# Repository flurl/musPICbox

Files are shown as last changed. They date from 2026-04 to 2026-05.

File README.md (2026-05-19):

# musPICbox

Dies ist das Sourcecode Repository zu meinem Artikel in [Make](https://www.heise.de/make) 3/26, Seite 88.

Außerdem finden Sie hier eine detailiertere Anleitung zum Konfigurieren des µC mit dem MPLAB Code Configurator.

Make Magazin Logo (https://www.heise.de/make)

## Konfiguration des PIC mittels MCC

Der MPLAB Code Configurator ermöglicht die grafische Konfiguration diverser Peripherie (Clock, Timer, ADC, PWM etc.) des Microcontrollers per Mausklick. Aus den getroffenen Einstellungen erzeugt der MCC Initialisierungscode, der die Register korrekt setzt und Helferfunktionen bereitstellt.

Die Konfiguration der Pins für die LEDs veranschaulicht diesen Prozess. Nach dem Start des MCC befindet man sich in dessen Hauptfenster, dem `Application Builder`. Hier wird eine grafische Repräsentation der Firmware angezeigt. Der oberste Abschnitt zeigt alle vom User hinzugefügten Komponenten an. Momentan ist das nur die Datei `main.c`. Der mit `System` beschriftete Bereich listet die in Verwendung befindlichen System Treiber. Darunter ist der Device Abschnitt, der Infos über die MCU und ihre Fähigkeiten anzeigt. Die weißen ? auf blauen Hintergrund führen direkt zur Online Dokumentation der jeweiligen Komponenten oder UI-Elemente - sehr praktisch.

Durch einen Klick auf den `Pins` System Treiber öffnet man die `Pin Package View`. Links oben gibt es ein mit "Package" beschriftetes Drop-Down, womit man die Gehäuseform des µC festlegen kann. Wir wählen PDIP20, woraufhin im Arbeitsbereich ein Piktogramm des Chips dargestellt wird. Dem Schaltplan ist zu entnehmen, dass die LEDs mit den GPIOs `RC0`, `RC1` sowie `RC2` verbunden werden. Um dies dem MCC mitzuteilen, klicken wir nacheinander auf die entsprechenden Pins des Symbolbildes, woraufhin ein Pop-Up erscheint, mit dem wir den Pins die Funktion "GPIO | GPIO | Output" zuweisen. Daraufhin wird für jeden Pin im rechten Fenster eine Zeile zur weiteren Konfiguration hinzugefügt. In der Spalte `Custom Name` kann man einen Alias für den jeweiligen IO-Port hinterlegen, den man im Quellcode verwenden kann. Ich habe ihnen dem Schaltplan entsprechend die Namen "LED_RED", "LED_BLUE" und "LED_GREEN" zugewiesen . Außerdem ist bei allen drei LED Pins die Option `Start High` zu aktivieren. Die sorgt dafür, dass die Pins beim Booten bereits auf High gesetzt werden, was, da die LEDs "active-low" verdrahtet sind, den Effekt hat, dass keine der LEDs leuchtet.

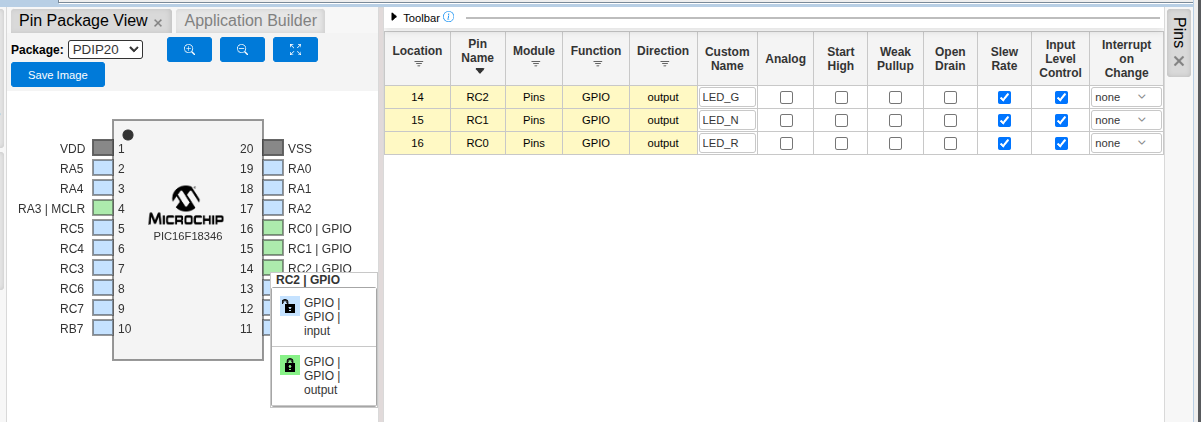
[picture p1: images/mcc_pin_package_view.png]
MCC Pin Package View label:mcc_pin_package_view


Danach wählt man am linken Rand des MCC den Tab `Project Resource` und klickt auf den blauen Button `Generate` im linken oberen Eck. Im `Output` Fenster sieht man, welche Aktionen der MCC sodann ausführt. So erstellt er diverse Dateien im Unterverzeichnis `mmcc_generated_files/system`. In eben jenem Verzeichnis findet sich nun auch eine Datei `pins.h`. Deren Inhalt illustriert, welche Arbeit der MCC für einen übernimmt. Vor allem erstellt der MCC eine Menge Präprozessordirektiven, die uns das lästige direkte hantieren mit den Registern des Prozessors ersparen und den Umgang mit der Peripherie wesentlich vereinfachen.

Die Zeile

```C
#define LED_RED_SetHigh() do { LATCbits.LATC0 = 1; } while(0)
```

ermöglicht es beispielsweise, den Pin, an dem die rote LED hängt (hier kommen die `Custom Names` ins Spiel), durch ein simples `LED_RED_SetHigh()` im C-Code auf High zu setzen. Das Macro `LED_RED_SetHigh()` wird dabei durch den etwas seltsam anmutenden `do ... while(0)` Block ersetzt. Dieser setzt des Bit 0 im `LATC` Register auf 1 und damit den Pin auf High. Die Konstruktion mit der do-while-Schleife hat syntaktische Gründe.

Der MCC ist auch die passende Anlaufstelle um die Frequenz, mit der µC läuft einzustellen. Die Frequenzen, die wir für die Erzeugung der Töne benötigen, liegen im niedrigen kHz Bereich. Es ergibt daher wenig sinn, den PIC mit vollem Speed laufen zu lassen. Je langsamnr, desto niedriger der Stromverbrauch. Ein Klick auf das `Clock Control` Modul ermöglicht es, den Takt mit dem Dropdown `HF Internal Clock` auf 1MHz zu setzen.

Um die weiteren GPIOs zu konfigurieren gehen wir nach dem selben Muster vor. Dem Schaltplan nach wird der Taster mit dem Pin `RA2` verbunden. Also klicken wir im `Pin Package View` des MCC auf das Symbol des entsprechenden Pins und weisen ihm die Funktion "GPIO | Input" zu. Als `Custom Name` verwende ich "PIN_BTN". Außerdem setze ich das Häckchen bei `Weak Pullup`, womit der interen Pullup Widerstand aktiviert wird.

Damit ist der "einfache" Part der Konfiguration erledigt. Nun gilt es noch zwei Probleme zu lösen. Das erste ist, dass, um eine wirklich (pseudo)-zufällige Wiedergabe zu ermöglichen, wir noch einen Seed für den Zufallsgenerator benötigen. Dafür machen wir uns einen floatenden analogen Eingang zu nutze. Floatend bedeutet, dass er nicht weiter verdrahtet und somit nur einem Zufallsrauschen ausgesetzt ist. Dafür müssen wir zuerst ins `Application Builder` Fenster zurück und mittels des Knopfes `⊕Add Component` den Add Component Dialog aufrufen. Am besten filtert man in diesem die Liste der verfügbaren Komponenten, indem man ins Suchfeld den Begriff "ADC" eingibt. In den Suchergebnissen klickt man schließlich in der Zeile des ADC Moduls ganz rechts auf das ⊕ Symbol, woraufhin sich der Dialog schließt und im `Application Builder` View das neu hinzugefügte Modul unter Main angezeigt wird. Mit dem blauen Zahnradsymbol in der rosanen Komponentenbox gelangt man zur Konfiguation des ADC. Wir belassen alles auf den Standardwerten, aber ein Blick auf die angebotenen Möglichkeiten lohnt sich allemal.

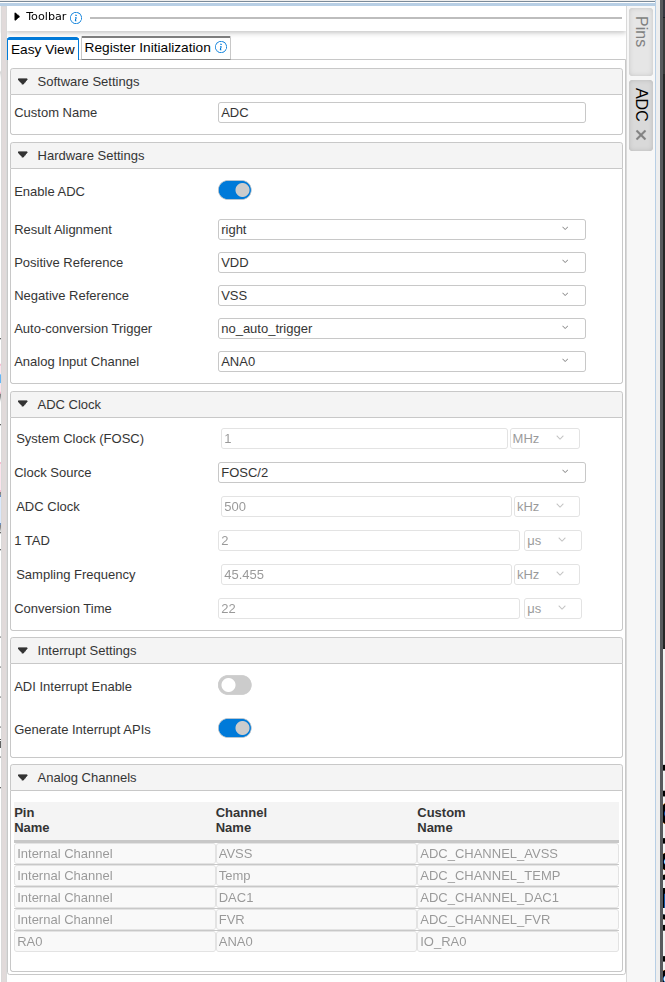
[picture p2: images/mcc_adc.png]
MCC ADC Konfiguration label:mcc_adc


Im `Pins`-Reiter sieht man auch, dass der Pin `RA0` automatisch dem ADC Modul zugewiesen wurde.

Was jetzt noch fehlt sind die zwei Pins, die das PWM Signal ausgeben sollen. Dazu sind zwei weitere Komponenten notwendig, die man wieder im `Application Builder` mittels `⊕Add Component` hinzufügen kann. Das erste ist das "CCP1" (Capture/Compare/PWM) Modul, das zweite heißt "CLC1" (Configurable Logic Cell). Nach beiden sucht man im Add Component Dialog und inkludiert sie ins Projekt mit ⊕.

Das blaue Zahnradsymbol beim "CCP1" Modul öffnet dessen Konfigurationsoptionen am rechten Rand. Den `CCP Mode` setzen wir auf PWM, was neue Optionen zum Vorschein bringt. Wählen wir nun im `TMR Dependency Selector` "TMR2" aus, wird der Timer2 als Abhängigkeit zu den Projektresourcen hinzugefügt (Reiter am linken Rand des MCC). Da die PWM und Timer Konfiguration dynamisch während des Programmablaufs geändert wird, können wir die restlichen Einstellungen auf dem Standard belassen.

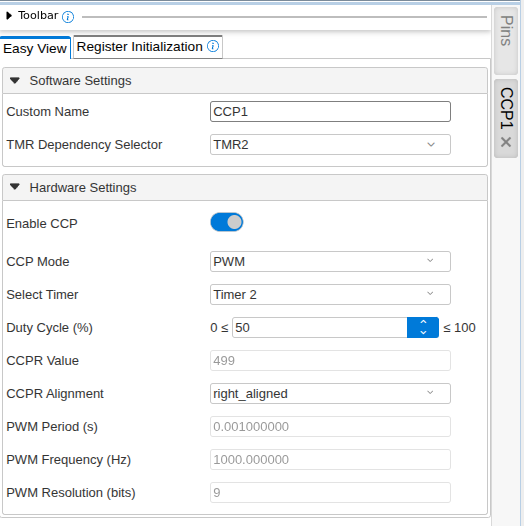
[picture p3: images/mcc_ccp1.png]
MCC Timer Konfiguration label:mcc_ccp1


Fehlt noch das CLC1 Modul. Wie bereits erwähnt, ermöglicht dieses, diverse Input Signale mit Logikblöcken zu verbinden und daraus ein Ausgangsignal zu generieren - ganz unabhängig vom Programmcode. Ein Klick auf die Komponente im `Application Builder` öffnet wiederum die Einstellungen des Moduls. Im `Logic Cell Mode bits` Dropdown bietet sich die "4-input-AND" Schaltung an. Sobald man sie ausgewählt hat, updated sich der Schaltplan im unteren Fenster und zeigt den Aufbau der Logikschaltung. Die mag auf den ersten Blick etwas ehrfurchtgebietend wirken, ist aber gar nicht kompliziert, wenn man sich in kleinen Schritten herantastet.

Unser Ziel ist es, das PWM Signal zu invertieren. Also ist es nur logisch, dass das PWM Signal als Input herhalten muss. Dafür reicht es, im ersten Dropdown den Ouptut des "CCP1" Moduls auszuwählen. Die erste Stufe der Schaltung besteht aus vier vierfach ODER Verknüpfungen, die zweite aus einer vierfach UND Verknüpfung und die dritte aus einem Buffer. Wenn man nun das Eingangssignal mit allen vier ODER Verknüpfungen verbindet, in dem man auf das strichlierte Quadrat auf der Eingangsseite der ODER Symbole klickt, bis sie mit dem Eingangssignal durch eine durchgehende Linie verbunden sind, wird das Signal direkt an alle vier Eingänge des AND Logikblocks angelegt. Das heißt, spuckt das "CCP1" eine 1 aus, liegt auch am Ausgang des ANDs eine 1 an. Diese wird nun noch durch den Buffer geschickt - der nichts anderes macht, als das Eingangssignal an seinen Ausgang durchzureichen - und wir erhalten am Ausgang der Logikzelle eine Kopie des Eingangssignals. Ziel fast erreicht; durch einen Klick auf das strichlierte Quadrat am Ausgang des Buffers fügen wir noch ein NOT-Gate hinzu, welches das Ausgangsignal des Buffers invertiert. Und somit ist nun das Ausgangssignal des "CLC1" Moduls stets invertiert zum PWM Signal.

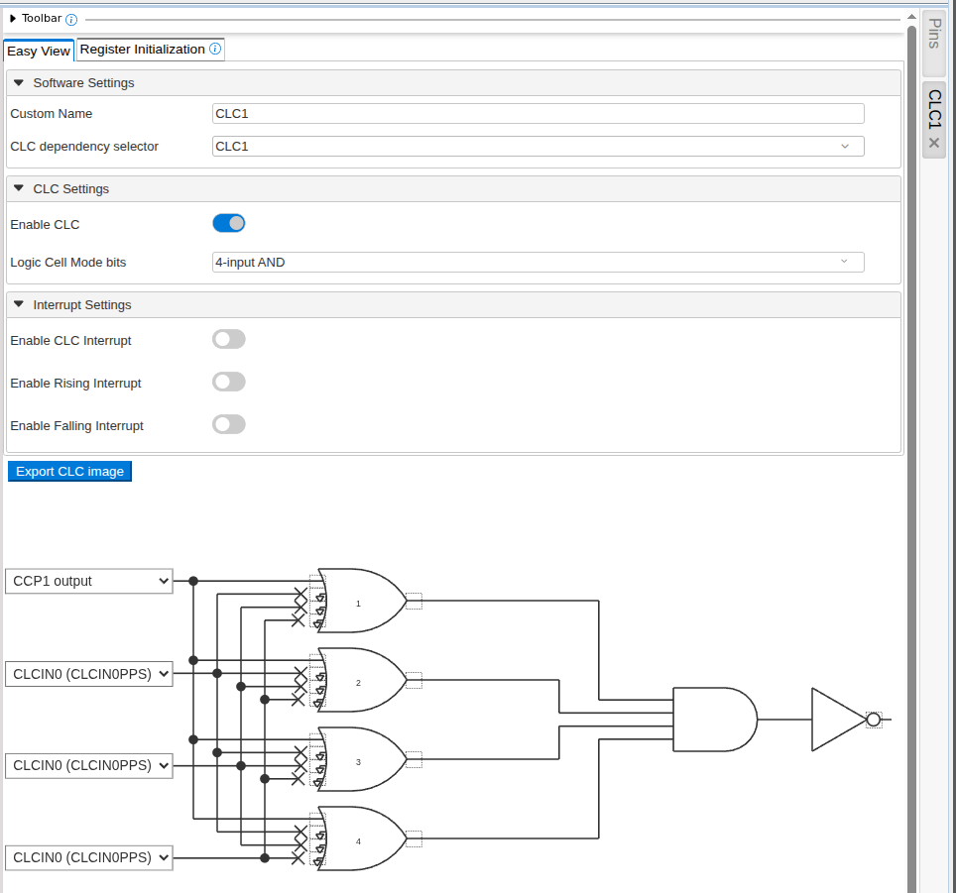
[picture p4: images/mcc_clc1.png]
CLC1 Konfiguration label:mcc_clc1


Als letzten Schritt müssen noch die Ausgänge der Module den entsprechenden Pins zugewiesen werden. Also zurück zur `Pin Package View`. Der Buzzer ist laut Schaltplan mit den Pins `RC3` und `RC4` verbunden. Deshalb weisen wir einem von ihnen "CCP1 | CCP1OUT | output" zu, und dem anderen "CLC1 | CLC1 | output". Welcher welche Rolle übernimmt ist egal, da sie immer gegengleich betrieben werden.

Somit ist das Setup im MCC abgeschlossen und mit der `Generate`-Schaltfläche lassen wir die notwendigen Dateien vom MCC erzeugen.

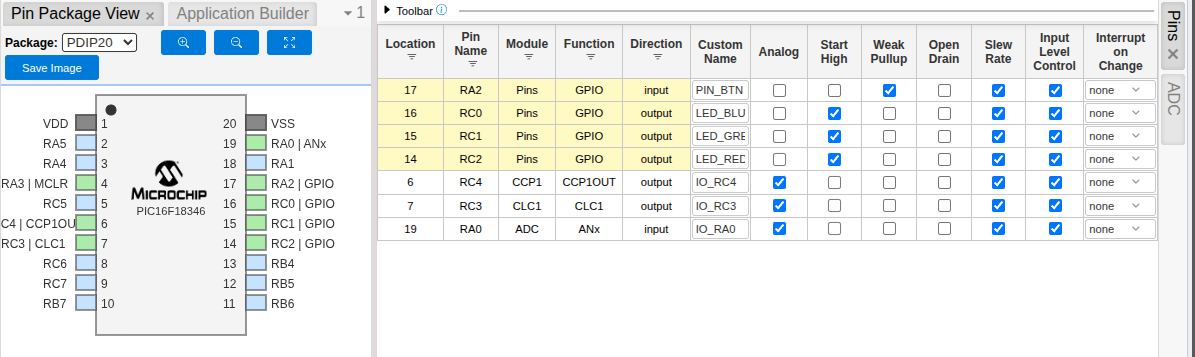
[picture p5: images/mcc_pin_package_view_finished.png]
MCC Pin Package View Einstellungen label:mcc_pin_package_view_finished


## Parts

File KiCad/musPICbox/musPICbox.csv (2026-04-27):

Id | Designator | Footprint | Quantity | Designation | Supplier and ref
1 | D8 | D_SOD-323_HandSoldering | 1 | D_Zener 5.1V
2 | D5,D7,D6,D4 | D_SMA_Handsoldering | 4 | D_Schottky
3 | D9 | LED_RGB_Wuerth-PLCC4_3.2x2.8mm_150141M173100 | 1 | LED_ARGB
4 | C1 | CP_Elec_10x10.5 | 1 | 1000µ
5 | BZ1 | JST_GH_BM02B-GHS-TBT_1x02-1MP_P1.25mm_Vertical | 1 | Buzzer
6 | R1 | R_0805_2012Metric_Pad1.20x1.40mm_HandSolder | 1 | 470
7 | C2 | C_0805_2012Metric_Pad1.18x1.45mm_HandSolder | 1 | 0.1µ
8 | M1 | JST_GH_BM02B-GHS-TBT_1x02-1MP_P1.25mm_Vertical | 1 | Motor_DC
9 | SW1 | JST_GH_BM02B-GHS-TBT_1x02-1MP_P1.25mm_Vertical | 1 | SW_Push
10 | U1 | DIP-20_W7.62mm | 1 | PIC16F18346-P

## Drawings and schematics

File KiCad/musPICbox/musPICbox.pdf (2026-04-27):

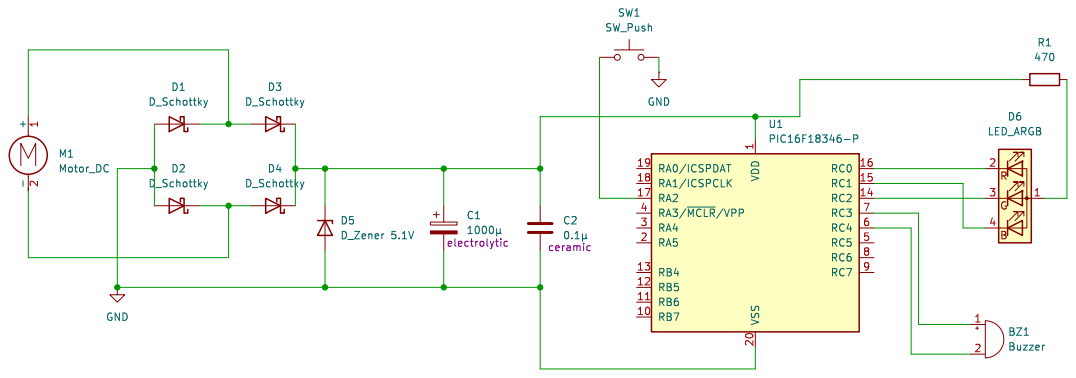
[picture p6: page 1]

Id: 1/1 Title: File: musPICbox.kicad_sch Sheet: /

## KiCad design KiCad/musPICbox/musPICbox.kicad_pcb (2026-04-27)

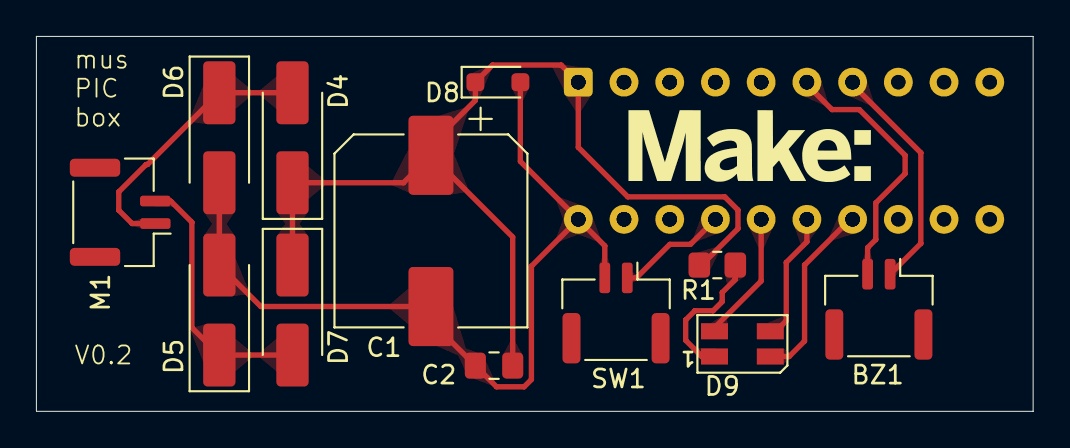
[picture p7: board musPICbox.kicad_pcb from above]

Board: 2 copper layers, 55.4 x 20.8 mm, 13 parts (1 on the bottom side), 11 nets.

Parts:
BZ1: Buzzer; JST_GH_BM02B-GHS-TBT_1x02-1MP_P1.25mm_Vertical
C1: 1000µ; CP_Elec_10x10.5
C2: 0.1µ; C_0805_2012Metric_Pad1.18x1.45mm_HandSolder
D4, D5, D6, D7: D_Schottky; D_SMA_Handsoldering
D8: D_Zener 5.1V; D_SOD-323_HandSoldering
D9: LED_ARGB; LED_RGB_Wuerth-PLCC4_3.2x2.8mm_150141M173100
M1: Motor_DC; JST_GH_BM02B-GHS-TBT_1x02-1MP_P1.25mm_Vertical
R1: 470; R_0805_2012Metric_Pad1.20x1.40mm_HandSolder
SW1: SW_Push; JST_GH_BM02B-GHS-TBT_1x02-1MP_P1.25mm_Vertical
U1: PIC16F18346-P; DIP-20_W7.62mm

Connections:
GND: C1.2, C2.2, D4.2 (A), D5.2 (A), D8.2 (A), SW1.2, U1.20 (VSS)
unnamed: BZ1.1 (+), U1.7 (RC3)
unnamed: BZ1.2 (-), U1.6 (RC4)
unnamed: D4.1 (K), D6.2 (A), M1.1 (+)
unnamed: D5.1 (K), D7.2 (A), M1.2 (-)
unnamed: C1.1, C2.1, D6.1 (K), D7.1 (K), D8.1 (K), R1.2, U1.1 (VDD)
unnamed: D9.1 (A), R1.1
unnamed: D9.4 (BK), U1.15 (RC1)
unnamed: D9.3 (GK), U1.14 (RC2)
unnamed: D9.2 (RK), U1.16 (RC0)
unnamed: SW1.1, U1.17 (RA2)

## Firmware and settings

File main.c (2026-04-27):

 /*
 * MAIN Generated Driver File
 * 
 * @file main.c
 * 
 * @defgroup main MAIN
 * 
 * @brief This is the generated driver implementation file for the MAIN driver.
 *
 * @version MAIN Driver Version 1.0.2
 *
 * @version Package Version: 3.1.2
*/

/*
? [2026] Microchip Technology Inc. and its subsidiaries.

    Subject to your compliance with these terms, you may use Microchip 
    software and any derivatives exclusively with Microchip products. 
    You are responsible for complying with 3rd party license terms  
    applicable to your use of 3rd party software (including open source  
    software) that may accompany Microchip software. SOFTWARE IS ?AS IS.? 
    NO WARRANTIES, WHETHER EXPRESS, IMPLIED OR STATUTORY, APPLY TO THIS 
    SOFTWARE, INCLUDING ANY IMPLIED WARRANTIES OF NON-INFRINGEMENT,  
    MERCHANTABILITY, OR FITNESS FOR A PARTICULAR PURPOSE. IN NO EVENT 
    WILL MICROCHIP BE LIABLE FOR ANY INDIRECT, SPECIAL, PUNITIVE, 
    INCIDENTAL OR CONSEQUENTIAL LOSS, DAMAGE, COST OR EXPENSE OF ANY 
    KIND WHATSOEVER RELATED TO THE SOFTWARE, HOWEVER CAUSED, EVEN IF 
    MICROCHIP HAS BEEN ADVISED OF THE POSSIBILITY OR THE DAMAGES ARE 
    FORESEEABLE. TO THE FULLEST EXTENT ALLOWED BY LAW, MICROCHIP?S 
    TOTAL LIABILITY ON ALL CLAIMS RELATED TO THE SOFTWARE WILL NOT 
    EXCEED AMOUNT OF FEES, IF ANY, YOU PAID DIRECTLY TO MICROCHIP FOR 
    THIS SOFTWARE.
*/
#include <stdlib.h>

#include "mcc_generated_files/system/system.h"
#include "random.h"
#include "melodies.h"

// the melody that should be played when the button is pressed at startup
#define SIGNATURE_MELODY 0


inline void delay(uint32_t ms) {
    for (uint32_t i=1; i<=ms; i++) {
        __delay_ms(1);
    }
}


void seed_RNG() {
    uint32_t seed = 0;
    ADC_Enable();
    for (uint8_t i=0; i<32; i++) {
        ADC_ConversionStart();
        while(!ADC_IsConversionDone());
        seed |= ((ADC_ConversionResultGet() & 0x01) << i);
    }
    ADC_Disable();
    rng_seed(seed);
}


pitch_t get_max_pitch(const struct Note *notes, uint16_t size) {
    pitch_t max = 0;
    for (uint16_t i=0; i<size; i++) {
        if (notes[i].pitch > max) {
            max = notes[i].pitch;
        }
    }
    return max;
}

pitch_t get_min_pitch(const struct Note *notes, uint16_t size) {
    pitch_t min = 0xFFFF;
    for (uint16_t i=0; i<size; i++) {
        pitch_t p = notes[i].pitch;
        if (p < min && p != REST) {
            min = notes[i].pitch;
        }
    }
    return min;
}

void tone(pitch_t tone) {
    
    setup_pitch(tone);
    
}

void play_melody(const struct Melody *melody) {
    size_t length = melody->length;  
    pitch_t max = get_max_pitch(melody->notes, length);
    pitch_t min = get_min_pitch(melody->notes, length);
    pitch_t low_threshold = (max-min)/3 + min;
    pitch_t high_threshold = ((max-min)/3)*2 + min;
    
    for (int current_note = 0; current_note < length; current_note++) {
        if (PIN_BTN_GetValue() == LOW) {
            delay(1000);
            return;
        }
        struct Note n = melody->notes[current_note];
        tone(n.pitch);
        if (n.pitch > 0 && n.pitch < low_threshold) {LED_BLUE_SetLow();}
        else if (n.pitch >= low_threshold && n.pitch < high_threshold) {LED_GREEN_SetLow();}
        else if (n.pitch >= high_threshold) {LED_RED_SetLow();}
        delay((uint32_t)((melody->speed*n.value)>>5));
        LED_RED_SetHigh();
        LED_GREEN_SetHigh();
        LED_BLUE_SetHigh();
        tone(REST);
        delay(10);
    }
}


/*
    Main application
*/

int main(void)
{
    SYSTEM_Initialize();
    
    seed_RNG();
    
    uint8_t selected_melody = SIGNATURE_MELODY;
    // if the button is not pressed at boot, randomly select the starting melody
    if (PIN_BTN_GetValue() == HIGH) {
        selected_melody = (uint8_t)rng_uniform(NUM_MELODIES);
    }
    
    tone(NOTE_A4);
    LED_BLUE_SetLow();
    __delay_ms(300);
    LED_BLUE_SetHigh();
    tone(NOTE_A5);
    LED_GREEN_SetLow();
    __delay_ms(300);
    LED_GREEN_SetHigh();
    tone(NOTE_A6);
    LED_RED_SetLow();
    __delay_ms(300);
    LED_RED_SetHigh();
   
    tone(REST);
    delay(500);    
    
    while(1) {
        play_melody(&(melodies[selected_melody]));
        delay(1000);    
        selected_melody = (uint8_t)rng_uniform(NUM_MELODIES);
    }
}

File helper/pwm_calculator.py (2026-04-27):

# pwm_calculator.py

# This script calculates the optimal PR2 value and TMR2 prescaler
# for a desired PWM frequency on a PIC16F18326 microcontroller.

# The core formula for PWM frequency is:
# F_PWM = F_OSC / (4 * (PR2 + 1) * TMR2_Prescaler)
# We rearrange this to solve for PR2:
# PR2 = (F_OSC / (4 * F_PWM * TMR2_Prescaler)) - 1

import math
import sys

def calculate_pwm_values(f_osc, f_pwm):
    """
    Calculates the best PR2 and TMR2 prescaler values for a given frequency,
    finding the closest approximation if an exact solution is not available.

    Args:
        f_osc (float): The microcontroller's oscillator frequency in Hz.
        f_pwm (float): The desired PWM frequency in Hz.

    Returns:
        tuple or None: A tuple containing (PR2, prescaler, actual_f_pwm)
                       if a solution is found, otherwise None.
    """

    # List of possible TMR2 prescaler values
    prescalers = [1, 4, 16, 64]
    
    # List to store all valid solutions and their errors
    solutions = []

    # Iterate through each possible prescaler to find a valid PR2 value
    for prescaler in prescalers:
        # Check if F_PWM is zero to prevent division by zero errors
        if f_pwm == 0:
            continue
            
        # Calculate the required PR2 value as a float
        pr2_float = (f_osc / (4.0 * f_pwm * prescaler)) - 1
        
        # We use this method for rounding to ensure it behaves as expected,
        # especially with potential floating-point precision issues.
        pr2 = int(pr2_float + 0.5)
        
        # Check if the calculated integer PR2 is within the valid range (0-255)
        if 0 <= pr2 <= 255:
            # Calculate the actual PWM frequency for this combination
            actual_f_pwm = f_osc / (4.0 * (pr2 + 1) * prescaler)
            
            # Calculate the absolute difference (error)
            error = abs(f_pwm - actual_f_pwm)
            
            # Store the solution
            solutions.append({
                'pr2': pr2,
                'prescaler': prescaler,
                'actual_f_pwm': actual_f_pwm,
                'error': error
            })
            
    # If no solutions were found, return None
    if not solutions:
        return None
        
    # Find the solution with the smallest error
    best_solution = min(solutions, key=lambda x: x['error'])
    
    # Return the best PR2, prescaler, and the actual frequency
    return (best_solution['pr2'], best_solution['prescaler'], best_solution['actual_f_pwm'])

if __name__ == "__main__":
    try:
        # Check if command-line arguments were provided
        if len(sys.argv) == 3:
            # Use arguments if they exist
            f_osc = float(sys.argv[1]) * 1_000_000
            f_pwm = float(sys.argv[2]) * 1_000
        else:
            # Fall back to interactive input
            f_osc_input = input("Enter the oscillator frequency in MHz (e.g., 16): ")
            f_pwm_input = input("Enter the desired PWM frequency in kHz (e.g., 20): ")

            f_osc = float(f_osc_input) * 1_000_000  # Convert MHz to Hz
            f_pwm = float(f_pwm_input) * 1_000     # Convert kHz to Hz

        # Call the calculation function
        result = calculate_pwm_values(f_osc, f_pwm)

        if result:
            pr2, prescaler, actual_f_pwm = result
            print(f"    PR2 = {pr2};")
            if prescaler == 1:
                ps_bits = 0b00
            elif prescaler == 4:
                ps_bits = 0b01
            elif prescaler == 16:
                ps_bits = 0b10
            else:
                ps_bits = 0b11
            print(f"    T2CON = T2CON & 0b11111100 | ({ps_bits} << _T2CON_T2CKPS_POSN); // prescaler {prescaler}")
            print("    break;\n")
#            print("""
#    duty_cycle_reg_val = 0.5*4*(PR2+1);
#    CCPR1L = duty_cycle_reg_val & 255;
#    CCPR1H = duty_cycle_reg_val >> 8;
#    break;""")
#            print(f"\nSolution Found!")
#            print(f"Optimal PR2 Value: {pr2}")
#            print(f"Recommended Prescaler: {prescaler}")
#            print(f"This will give you a PWM frequency of approximately {actual_f_pwm / 1000:.2f} kHz.")
            
            # Calculate the error percentage
            error_percent = (abs(f_pwm - actual_f_pwm) / f_pwm) * 100
#            print(f"The error from the desired frequency is {error_percent:.2f}%.")
        else:
            print(f"\nNo valid combination of PR2 (0-255) and prescaler was found for the given frequencies.")
            print(f"Try adjusting the oscillator or desired PWM frequency.")

    except ValueError:
        print("\nInvalid input. Please enter numerical values for frequencies.")
    except Exception as e:
        print(f"\nAn error occurred: {e}")

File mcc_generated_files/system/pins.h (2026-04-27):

/**
 * Generated Pins header File
 * 
 * @file pins.h
 * 
 * @defgroup  pinsdriver Pins Driver
 * 
 * @brief This is generated driver header for pins. 
 *        This header file provides APIs for all pins selected in the GUI.
 *
 * @version Driver Version  3.0.0
*/

/*
© [2026] Microchip Technology Inc. and its subsidiaries.

    Subject to your compliance with these terms, you may use Microchip 
    software and any derivatives exclusively with Microchip products. 
    You are responsible for complying with 3rd party license terms  
    applicable to your use of 3rd party software (including open source  
    software) that may accompany Microchip software. SOFTWARE IS ?AS IS.? 
    NO WARRANTIES, WHETHER EXPRESS, IMPLIED OR STATUTORY, APPLY TO THIS 
    SOFTWARE, INCLUDING ANY IMPLIED WARRANTIES OF NON-INFRINGEMENT,  
    MERCHANTABILITY, OR FITNESS FOR A PARTICULAR PURPOSE. IN NO EVENT 
    WILL MICROCHIP BE LIABLE FOR ANY INDIRECT, SPECIAL, PUNITIVE, 
    INCIDENTAL OR CONSEQUENTIAL LOSS, DAMAGE, COST OR EXPENSE OF ANY 
    KIND WHATSOEVER RELATED TO THE SOFTWARE, HOWEVER CAUSED, EVEN IF 
    MICROCHIP HAS BEEN ADVISED OF THE POSSIBILITY OR THE DAMAGES ARE 
    FORESEEABLE. TO THE FULLEST EXTENT ALLOWED BY LAW, MICROCHIP?S 
    TOTAL LIABILITY ON ALL CLAIMS RELATED TO THE SOFTWARE WILL NOT 
    EXCEED AMOUNT OF FEES, IF ANY, YOU PAID DIRECTLY TO MICROCHIP FOR 
    THIS SOFTWARE.
*/

#ifndef PINS_H
#define PINS_H

#include <xc.h>

#define INPUT   1
#define OUTPUT  0

#define HIGH    1
#define LOW     0

#define ANALOG      1
#define DIGITAL     0

#define PULL_UP_ENABLED      1
#define PULL_UP_DISABLED     0

// get/set IO_RA0 aliases
#define IO_RA0_TRIS                 TRISAbits.TRISA0
#define IO_RA0_LAT                  LATAbits.LATA0
#define IO_RA0_PORT                 PORTAbits.RA0
#define IO_RA0_WPU                  WPUAbits.WPUA0
#define IO_RA0_OD                   ODCONAbits.ODCA0
#define IO_RA0_ANS                  ANSELAbits.ANSA0
#define IO_RA0_SetHigh()            do { LATAbits.LATA0 = 1; } while(0)
#define IO_RA0_SetLow()             do { LATAbits.LATA0 = 0; } while(0)
#define IO_RA0_Toggle()             do { LATAbits.LATA0 = ~LATAbits.LATA0; } while(0)
#define IO_RA0_GetValue()           PORTAbits.RA0
#define IO_RA0_SetDigitalInput()    do { TRISAbits.TRISA0 = 1; } while(0)
#define IO_RA0_SetDigitalOutput()   do { TRISAbits.TRISA0 = 0; } while(0)
#define IO_RA0_SetPullup()          do { WPUAbits.WPUA0 = 1; } while(0)
#define IO_RA0_ResetPullup()        do { WPUAbits.WPUA0 = 0; } while(0)
#define IO_RA0_SetPushPull()        do { ODCONAbits.ODCA0 = 0; } while(0)
#define IO_RA0_SetOpenDrain()       do { ODCONAbits.ODCA0 = 1; } while(0)
#define IO_RA0_SetAnalogMode()      do { ANSELAbits.ANSA0 = 1; } while(0)
#define IO_RA0_SetDigitalMode()     do { ANSELAbits.ANSA0 = 0; } while(0)
// get/set IO_RA2 aliases
#define PIN_BTN_TRIS                 TRISAbits.TRISA2
#define PIN_BTN_LAT                  LATAbits.LATA2
#define PIN_BTN_PORT                 PORTAbits.RA2
#define PIN_BTN_WPU                  WPUAbits.WPUA2
#define PIN_BTN_OD                   ODCONAbits.ODCA2
#define PIN_BTN_ANS                  ANSELAbits.ANSA2
#define PIN_BTN_SetHigh()            do { LATAbits.LATA2 = 1; } while(0)
#define PIN_BTN_SetLow()             do { LATAbits.LATA2 = 0; } while(0)
#define PIN_BTN_Toggle()             do { LATAbits.LATA2 = ~LATAbits.LATA2; } while(0)
#define PIN_BTN_GetValue()           PORTAbits.RA2
#define PIN_BTN_SetDigitalInput()    do { TRISAbits.TRISA2 = 1; } while(0)
#define PIN_BTN_SetDigitalOutput()   do { TRISAbits.TRISA2 = 0; } while(0)
#define PIN_BTN_SetPullup()          do { WPUAbits.WPUA2 = 1; } while(0)
#define PIN_BTN_ResetPullup()        do { WPUAbits.WPUA2 = 0; } while(0)
#define PIN_BTN_SetPushPull()        do { ODCONAbits.ODCA2 = 0; } while(0)
#define PIN_BTN_SetOpenDrain()       do { ODCONAbits.ODCA2 = 1; } while(0)
#define PIN_BTN_SetAnalogMode()      do { ANSELAbits.ANSA2 = 1; } while(0)
#define PIN_BTN_SetDigitalMode()     do { ANSELAbits.ANSA2 = 0; } while(0)
// get/set IO_RC0 aliases
#define LED_BLUE_TRIS                 TRISCbits.TRISC0
#define LED_BLUE_LAT                  LATCbits.LATC0
#define LED_BLUE_PORT                 PORTCbits.RC0
#define LED_BLUE_WPU                  WPUCbits.WPUC0
#define LED_BLUE_OD                   ODCONCbits.ODCC0
#define LED_BLUE_ANS                  ANSELCbits.ANSC0
#define LED_BLUE_SetHigh()            do { LATCbits.LATC0 = 1; } while(0)
#define LED_BLUE_SetLow()             do { LATCbits.LATC0 = 0; } while(0)
#define LED_BLUE_Toggle()             do { LATCbits.LATC0 = ~LATCbits.LATC0; } while(0)
#define LED_BLUE_GetValue()           PORTCbits.RC0
#define LED_BLUE_SetDigitalInput()    do { TRISCbits.TRISC0 = 1; } while(0)
#define LED_BLUE_SetDigitalOutput()   do { TRISCbits.TRISC0 = 0; } while(0)
#define LED_BLUE_SetPullup()          do { WPUCbits.WPUC0 = 1; } while(0)
#define LED_BLUE_ResetPullup()        do { WPUCbits.WPUC0 = 0; } while(0)
#define LED_BLUE_SetPushPull()        do { ODCONCbits.ODCC0 = 0; } while(0)
#define LED_BLUE_SetOpenDrain()       do { ODCONCbits.ODCC0 = 1; } while(0)
#define LED_BLUE_SetAnalogMode()      do { ANSELCbits.ANSC0 = 1; } while(0)
#define LED_BLUE_SetDigitalMode()     do { ANSELCbits.ANSC0 = 0; } while(0)
// get/set IO_RC1 aliases
#define LED_GREEN_TRIS                 TRISCbits.TRISC1
#define LED_GREEN_LAT                  LATCbits.LATC1
#define LED_GREEN_PORT                 PORTCbits.RC1
#define LED_GREEN_WPU                  WPUCbits.WPUC1
#define LED_GREEN_OD                   ODCONCbits.ODCC1
#define LED_GREEN_ANS                  ANSELCbits.ANSC1
#define LED_GREEN_SetHigh()            do { LATCbits.LATC1 = 1; } while(0)
#define LED_GREEN_SetLow()             do { LATCbits.LATC1 = 0; } while(0)
#define LED_GREEN_Toggle()             do { LATCbits.LATC1 = ~LATCbits.LATC1; } while(0)
#define LED_GREEN_GetValue()           PORTCbits.RC1
#define LED_GREEN_SetDigitalInput()    do { TRISCbits.TRISC1 = 1; } while(0)
#define LED_GREEN_SetDigitalOutput()   do { TRISCbits.TRISC1 = 0; } while(0)
#define LED_GREEN_SetPullup()          do { WPUCbits.WPUC1 = 1; } while(0)
#define LED_GREEN_ResetPullup()        do { WPUCbits.WPUC1 = 0; } while(0)
#define LED_GREEN_SetPushPull()        do { ODCONCbits.ODCC1 = 0; } while(0)
#define LED_GREEN_SetOpenDrain()       do { ODCONCbits.ODCC1 = 1; } while(0)
#define LED_GREEN_SetAnalogMode()      do { ANSELCbits.ANSC1 = 1; } while(0)
#define LED_GREEN_SetDigitalMode()     do { ANSELCbits.ANSC1 = 0; } while(0)
// get/set IO_RC2 aliases
#define LED_RED_TRIS                 TRISCbits.TRISC2
#define LED_RED_LAT                  LATCbits.LATC2
#define LED_RED_PORT                 PORTCbits.RC2
#define LED_RED_WPU                  WPUCbits.WPUC2
#define LED_RED_OD                   ODCONCbits.ODCC2
#define LED_RED_ANS                  ANSELCbits.ANSC2
#define LED_RED_SetHigh()            do { LATCbits.LATC2 = 1; } while(0)
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

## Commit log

2026-04-27 Add KiCad files
    [musPICbox.kicad_pcb, musPICbox.kicad_sch, musPICbox_V1.kicad_sch]
2026-04-27 Add BOM file
    [musPICbox.csv]
2026-05-19 Add README.md
    Added detailed instructions for configuring the PIC microcontroller using the MPLAB Code Configurator, including steps for setting up GPIOs, ADC, PWM, and logic cells.
